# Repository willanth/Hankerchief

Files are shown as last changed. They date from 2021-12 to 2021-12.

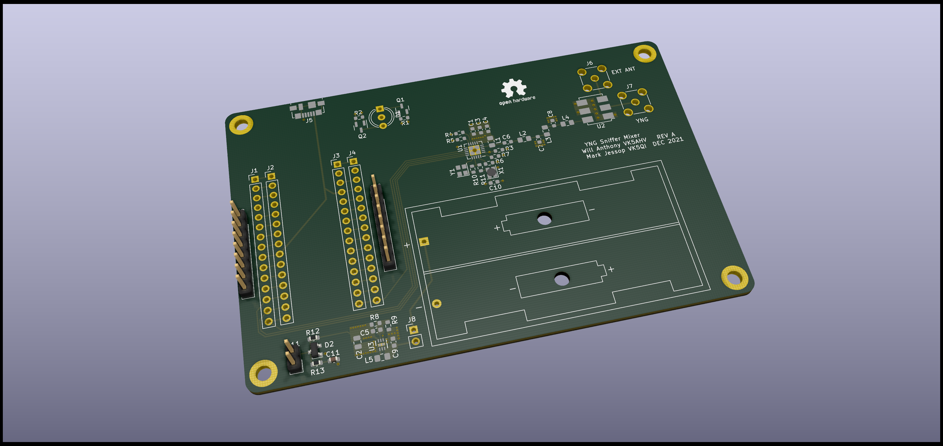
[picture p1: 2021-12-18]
sniffermixer2/sniffermixer2_RT.png

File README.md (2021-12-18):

# Hankerchief

This is a microcontroller driven signal source, used to extend the operating frequencies of the VK3YNG foxhunt sniffer.

The main components of this system are:
* STM32 Nuleo32 board (I used the L432KC) 
* Silabs Si4464 transciever chip
* ADE-1 mixer
* 3.3VDC boost converter suppled by 2x AA/LR6 batteries

There are provisions for user controls (J8 battery on/off, J11 shift frequency) as well as making use of the IO on the Nucleo module that isn't tied up operating the signal source.  There is a provsion for a bicolor LED, and for external 5V power input through a micro-B USB port.
**_IMPORTANT NOTE_**:  
* There is no battery charging facility through the USB power connector
* There is no USB Data access to the Nucleo32 through the USB power connector
* 3.3V Power is supplied by the Nucleo32 onboard regulator (500mA max) when USB power is connected
* The Nucleo32 is not configured for 5V supply and 3.3V source out of the box, it requires a simple modification (in Nucleo documentation, datasheets folder)

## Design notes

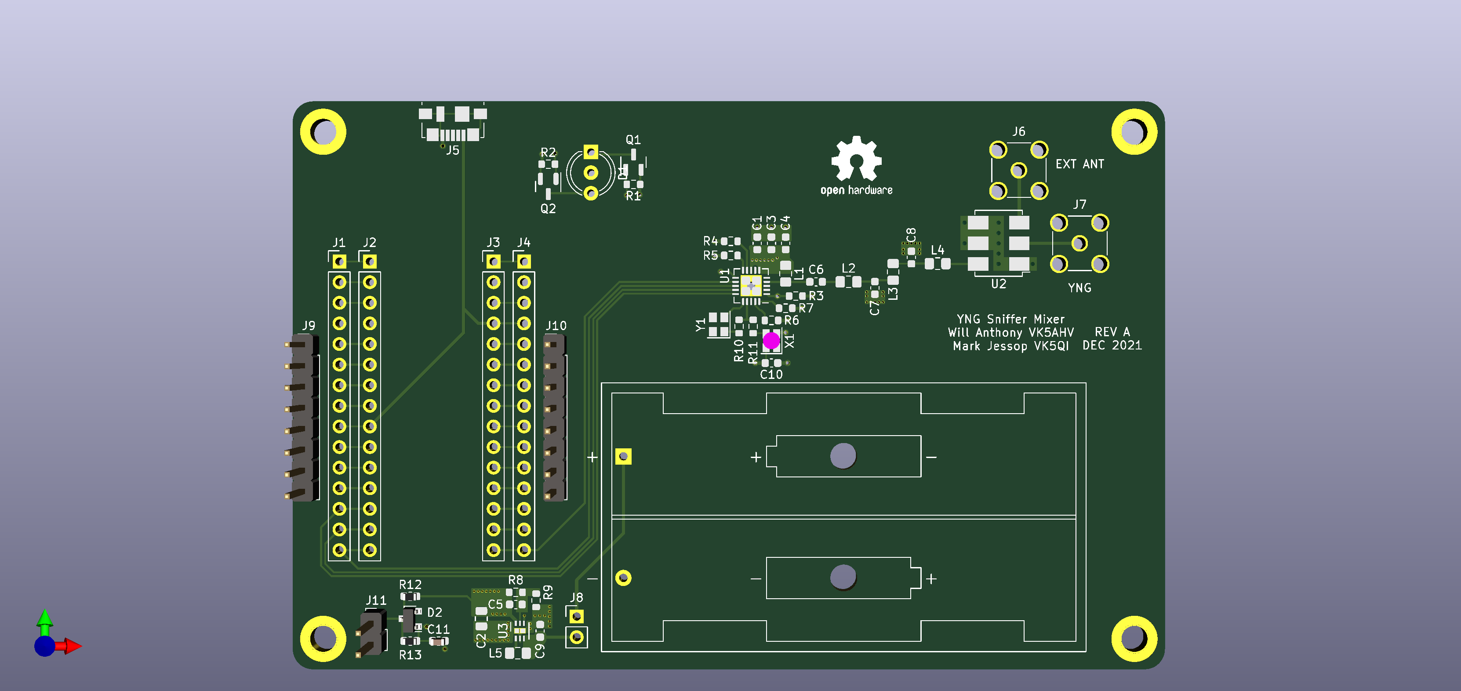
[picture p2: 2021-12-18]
sniffermixer2/sniffermixer2.png

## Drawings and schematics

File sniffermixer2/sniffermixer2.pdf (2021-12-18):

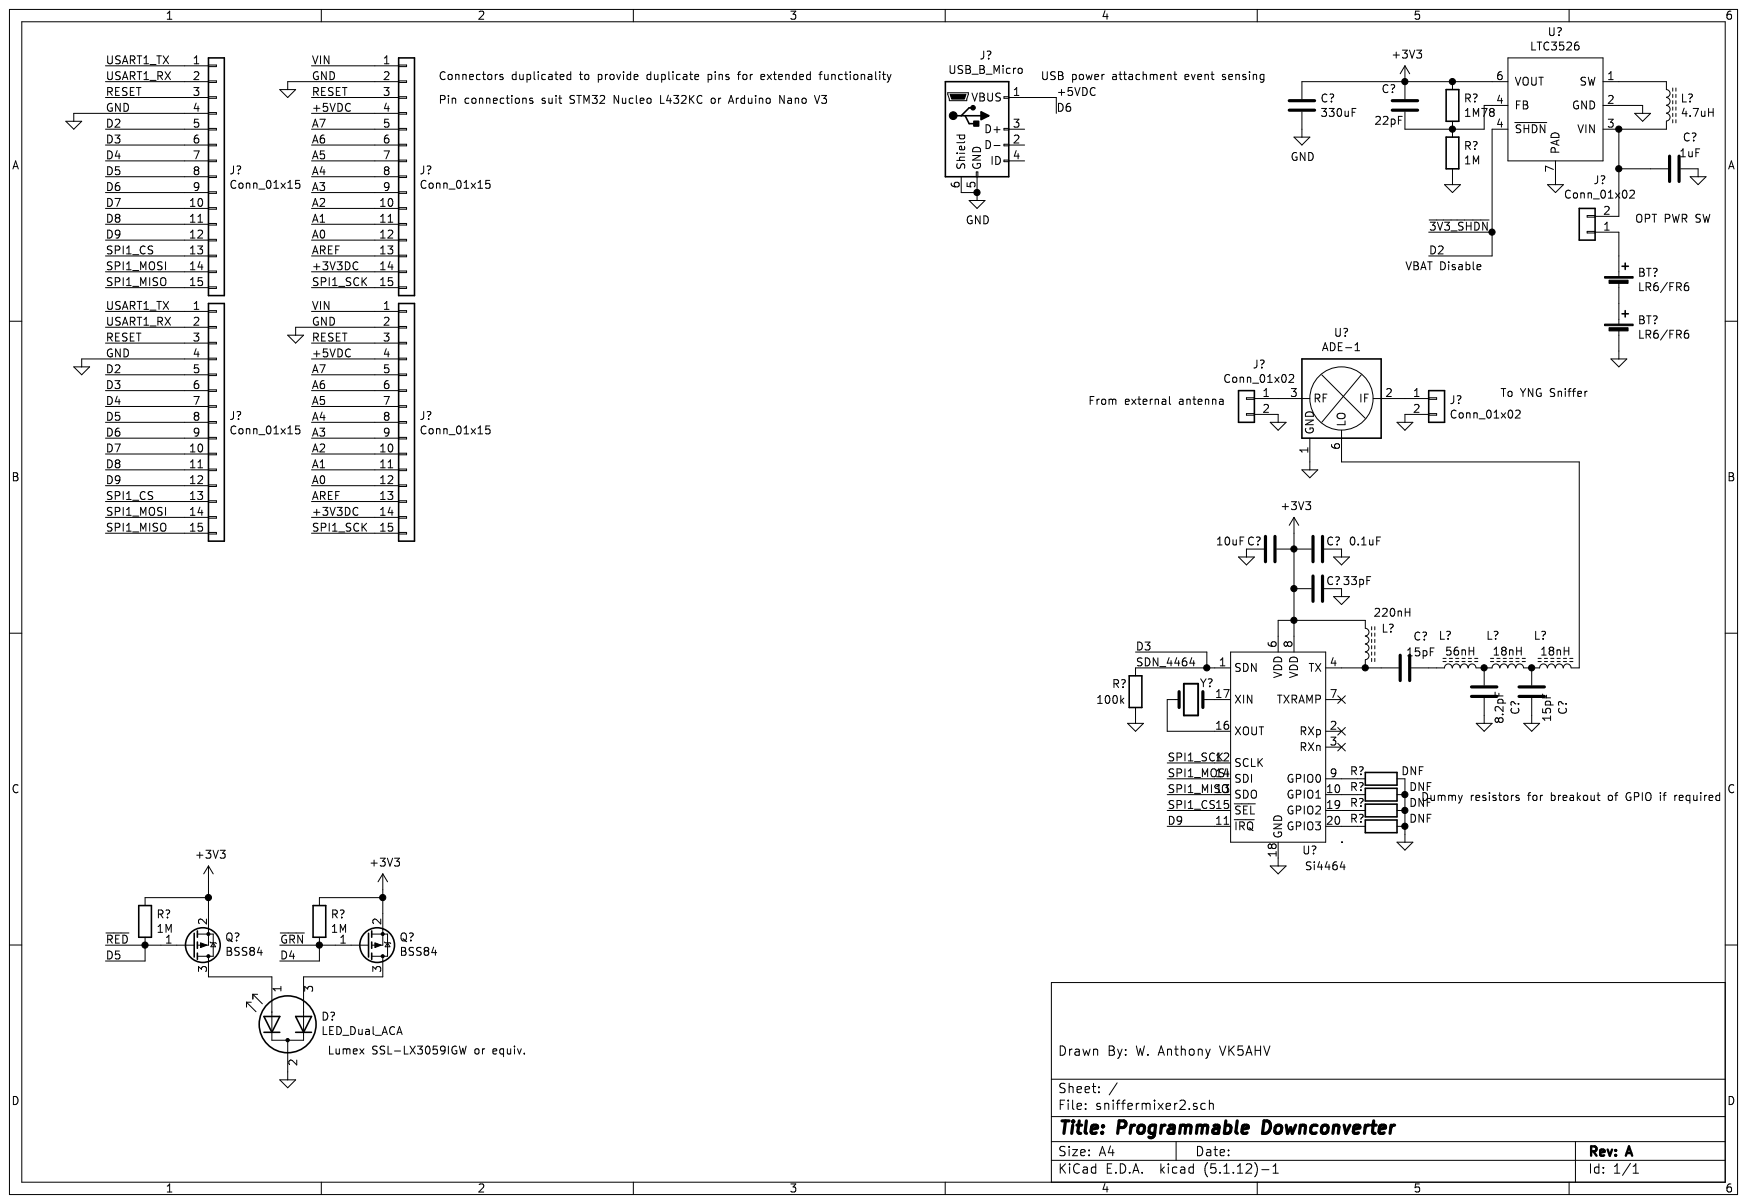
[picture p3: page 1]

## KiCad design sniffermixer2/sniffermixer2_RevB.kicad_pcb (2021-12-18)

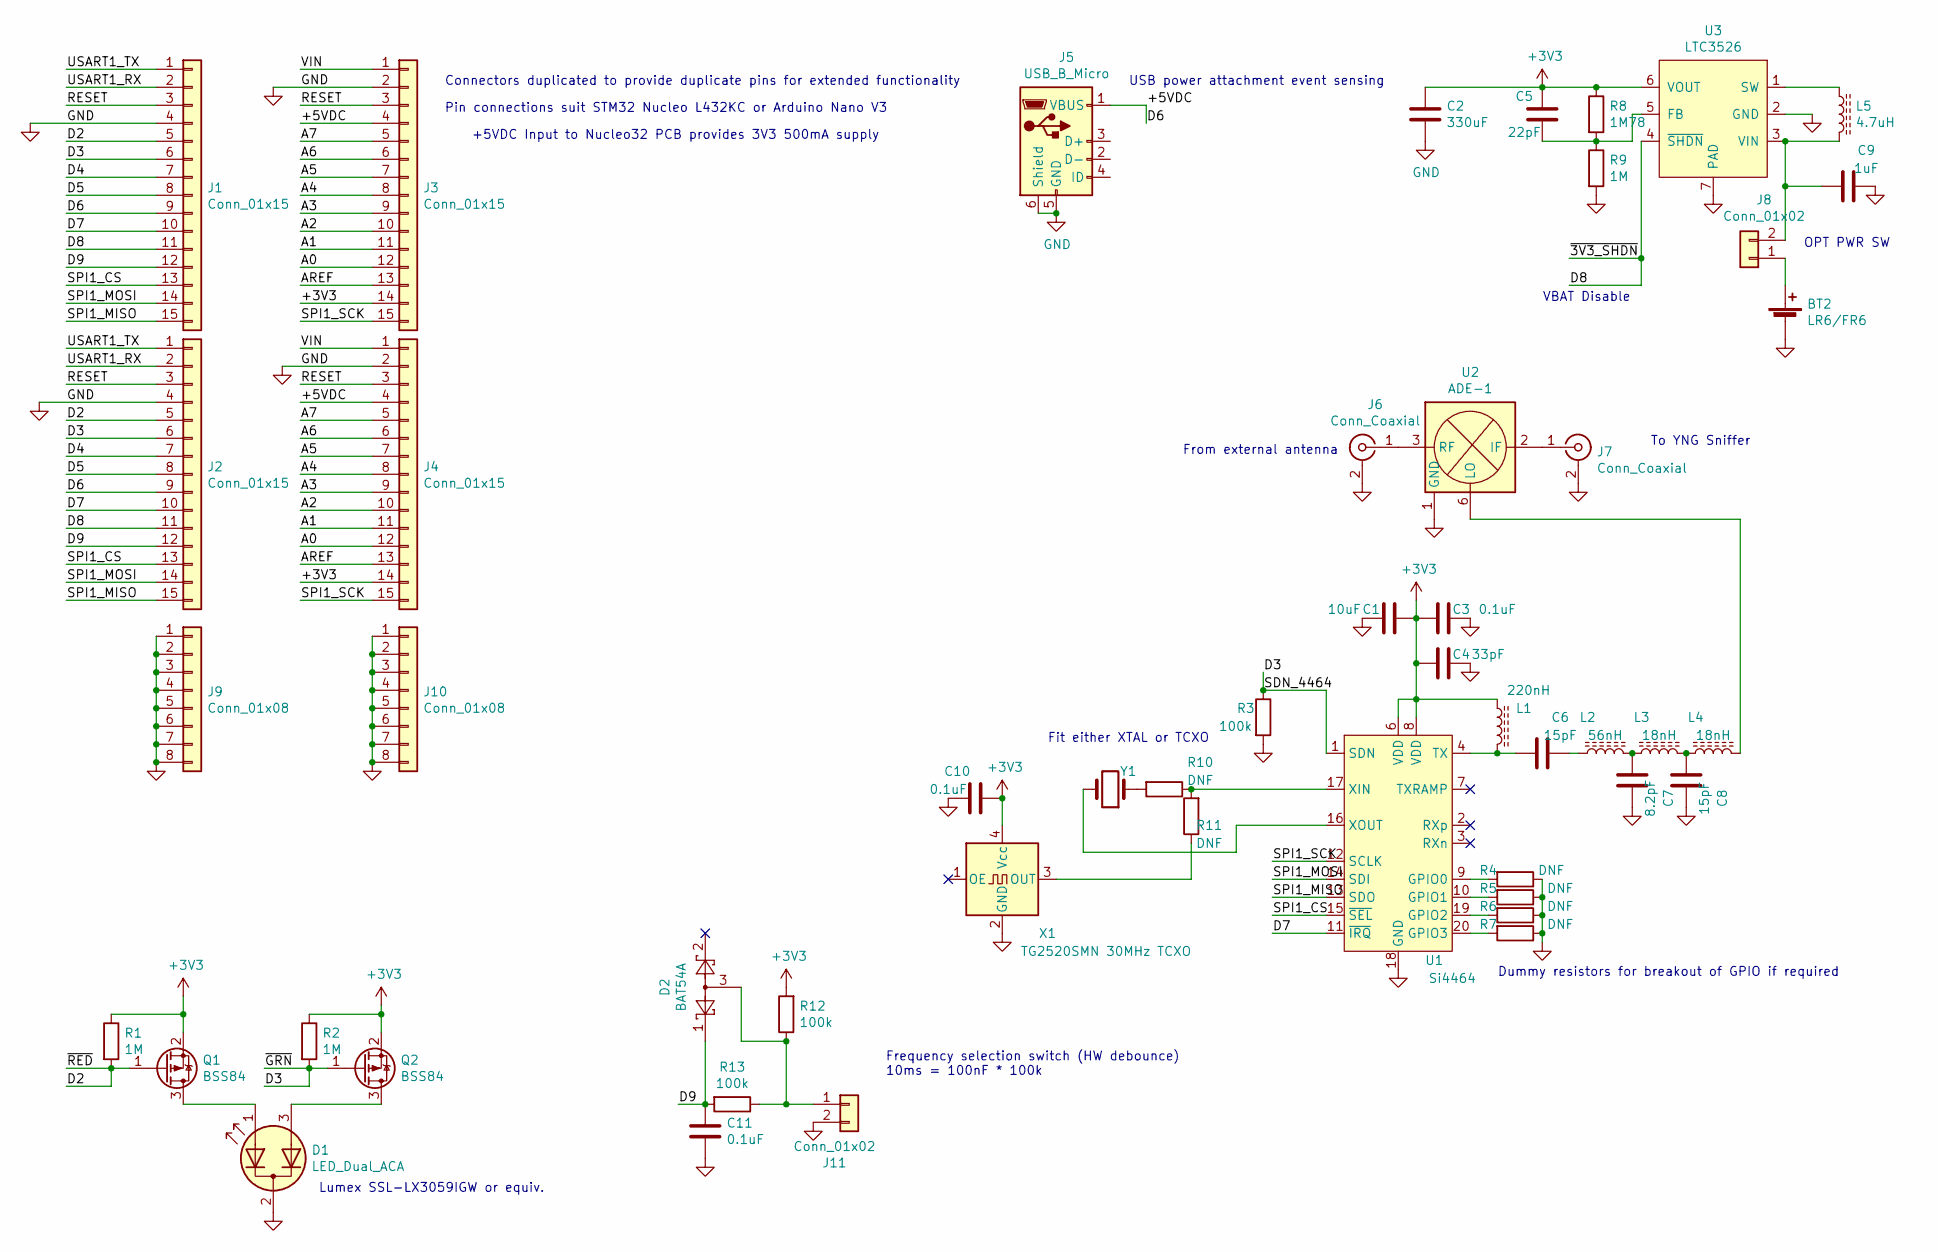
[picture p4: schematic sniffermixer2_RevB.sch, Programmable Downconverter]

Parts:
BT2: LR6/FR6; BatteryHolder_Keystone_2462_2xAA
C1: 10uF; C_0603_1608Metric
C2: 330uF; C_0805_2012Metric
C3, C10, C11: 0.1uF; C_0603_1608Metric
C4: 33pF; C_0603_1608Metric
C5: 22pF; C_0603_1608Metric
C6, C8: 15pF; C_0603_1608Metric
C7: 8.2pF; C_0603_1608Metric
C9: 1uF; C_0603_1608Metric
D1: LED_Dual_ACA; LED_D5.0mm-3
D2: BAT54A; SOT-23
J1, J2, J3, J4: Conn_01x15; PinHeader_1x15_P2.54mm_Vertical
J5: USB_B_Micro; USB_Micro-B_Molex_47346-0001
J6, J7: Conn_Coaxial; SMA_Amphenol_901-144_Vertical
J8, J11: Conn_01x02; PinHeader_1x02_P2.54mm_Vertical
J9, J10: Conn_01x08; PinHeader_1x08_P2.54mm_Vertical
L1: 220nH; L_0805_2012Metric_Pad1.15x1.40mm_HandSolder
L2: 56nH; L_0805_2012Metric_Pad1.15x1.40mm_HandSolder
L3, L4: 18nH; L_0805_2012Metric_Pad1.15x1.40mm_HandSolder
L5: 4.7uH; L_0805_2012Metric_Pad1.15x1.40mm_HandSolder
Q1, Q2: BSS84; SOT-23
R1, R2, R9: 1M; R_0603_1608Metric
R3, R12, R13: 100k; R_0603_1608Metric
R4, R5, R6, R7, R10, R11: DNF; R_0603_1608Metric
R8: 1M78; R_0603_1608Metric
U1: Si4464; QFN-20-1EP_4x4mm_P0.5mm_EP2.6x2.6mm
U2: ADE-1; Mini-Circuits_CD542_LandPatternPL-052
U3: LTC3526; DFN-6-1EP_2x2mm_P0.5mm_EP0.61x1.42mm
X1: TG2520SMN 30MHz TCXO; Oscillator_SMD_SeikoEpson_SG210-4Pin_2.5x2.0mm
Y1: Crystal; Crystal_SMD_2520-4Pin_2.5x2.0mm

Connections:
+3V3: C1.1, C2.1, C3.2, C4.2, C5.2, C10.2, J3.14, J4.14, L1.1, Q1.2 (S), Q2.2 (S), R1.1, R2.1, R8.1, R12.2, U1.6 (VDD), U1.8 (VDD), U3.6 (VOUT), X1.4 (Vcc)
/+5VDC: J1.9, J2.9, J3.4, J4.4, J5.1 (VBUS)
/A0: J3.12, J4.12
/A1: J3.11, J4.11
/A2: J3.10, J4.10
/A3: J3.9, J4.9
/A4: J3.8, J4.8
/A5: J3.7, J4.7
/A6: J3.6, J4.6
/A7: J3.5, J4.5
/AREF: J3.13, J4.13
/D2: J1.5, J2.5, Q1.1 (G), R1.2
/D7: J1.10, J2.10, U1.11 (~IRQ)
/D9: C11.1, D2.1, J1.12, J2.12, R13.2
/RESET: J1.3, J2.3, J3.3, J4.3
/SPI1_CS: J1.13, J2.13, U1.15 (~SEL)
/SPI1_MISO: J1.15, J2.15, U1.13 (SDO)
/SPI1_MOSI: J1.14, J2.14, U1.14 (SDI)
/SPI1_SCK: J3.15, J4.15, U1.12 (SCLK)
/USART1_RX: J1.2, J2.2
/USART1_TX: J1.1, J2.1
/VIN: J3.1, J4.1
GND: BT2.2 (-), C1.2, C2.2, C3.1, C4.1, C7.1, C8.1, C9.1, C10.1, C11.2, D1.2 (K), J1.4, J2.4, J3.2, J4.2, J5.5 (GND), J5.6 (Shield), J6.2 (Ext), J7.2 (Ext), J9.1, J9.2, J9.3, J9.4, J9.5, J9.6, J9.7, J9.8, J10.1, J10.2, J10.3, J10.4, J10.5, J10.6, J10.7, J10.8, J11.2, R3.2, R4.1, R5.1, R6.1, R7.1, R9.2, U1.18 (GND), U1.21 (GND), U2.1 (GND), U2.4 (GND), U2.5 (GND), U3.2 (GND), U3.7 (PAD), X1.2 (GND)
unnamed: BT2.1 (+), J8.1
unnamed: C5.1, R8.2, R9.1, U3.5 (FB)
unnamed: C6.1, L2.1
unnamed: C6.2, L1.2, U1.4 (TX)
unnamed: C7.2, L2.2, L3.1
unnamed: C8.2, L3.2, L4.1
unnamed: C9.2, J8.2, L5.2, U3.3 (VIN)
unnamed: D1.1 (A1), Q1.3 (D)
unnamed: D1.3 (A2), Q2.3 (D)
unnamed: D2.3, J11.1, R12.1, R13.1
unnamed: J6.1 (In), U2.3 (RF)
unnamed: J7.1 (In), U2.2 (IF)
unnamed: L4.2, U2.6 (LO)
unnamed: L5.1, U3.1 (SW)
unnamed: R4.2, U1.9 (GPIO0)
unnamed: R5.2, U1.10 (GPIO1)
unnamed: R6.2, U1.19 (GPIO2)
unnamed: R7.2, U1.20 (GPIO3)
unnamed: R10.1, R11.2, U1.17 (XIN)
unnamed: R10.2, Y1.1
unnamed: R11.1, X1.3 (OUT)
unnamed: U1.16 (XOUT), Y1.2

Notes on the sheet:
Connectors duplicated to provide duplicate pins for extended functionality
Pin connections suit STM32 Nucleo L432KC or Arduino Nano V3
Lumex SSL-LX3059IGW or equiv.
To YNG Sniffer
From external antenna
USB power attachment event sensing
VBAT Disable
OPT PWR SW
Dummy resistors for breakout of GPIO if required
Fit either XTAL or TCXO
+5VDC Input to Nucleo32 PCB provides 3V3 500mA supply
Frequency selection switch (HW debounce) 10ms = 100nF * 100k

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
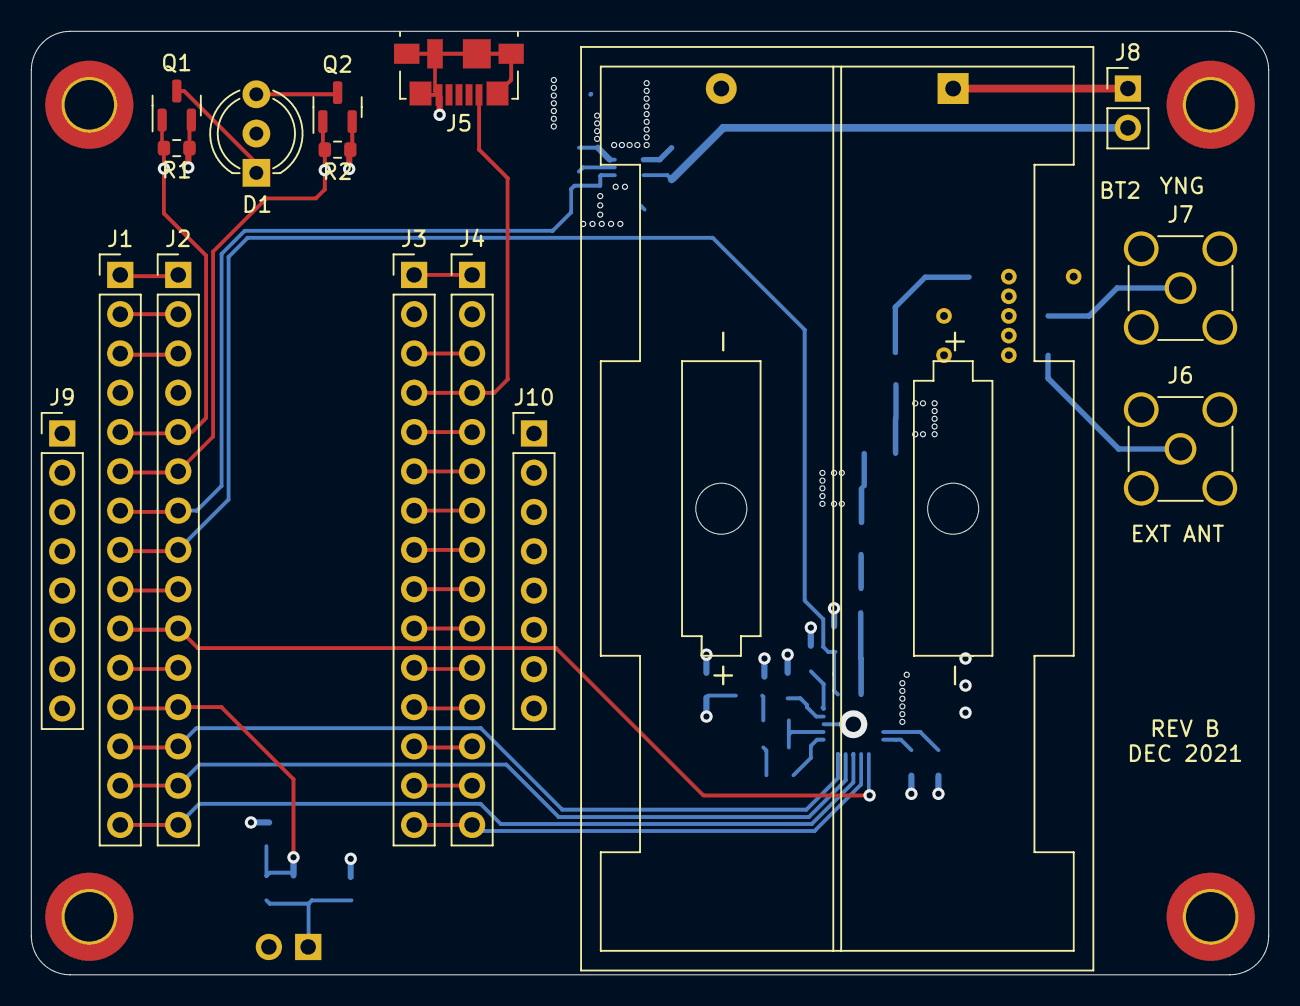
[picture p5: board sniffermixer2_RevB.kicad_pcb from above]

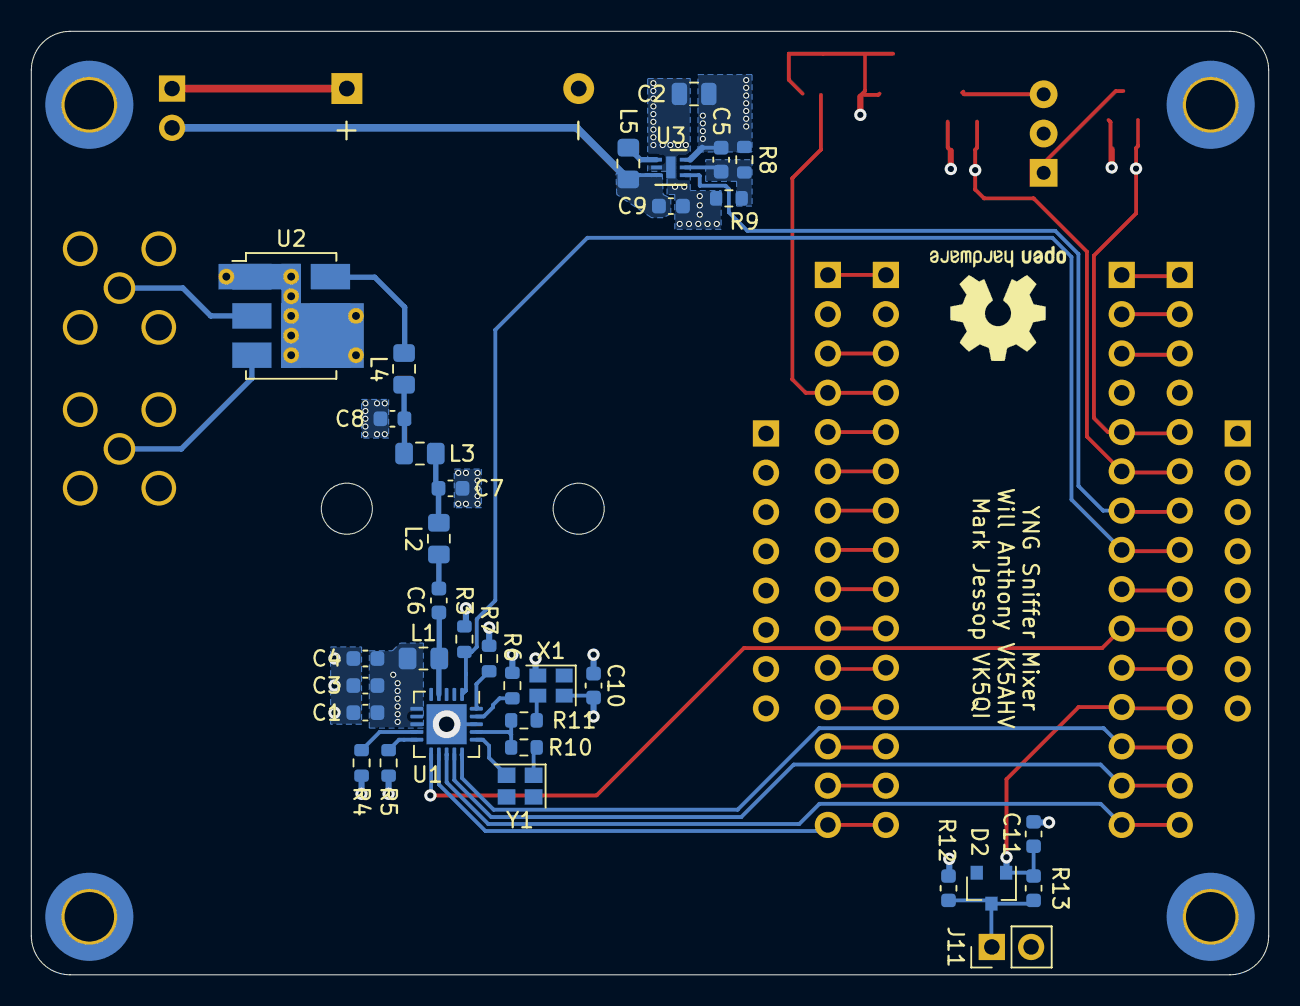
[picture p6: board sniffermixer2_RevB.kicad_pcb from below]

Board: 4 copper layers, 80.0 x 61.0 mm, 50 parts (34 on the bottom side), 49 nets.

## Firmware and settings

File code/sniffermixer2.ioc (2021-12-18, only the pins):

Mcu.UserName=STM32L432KCUx
PA0.GPIO_Label=MCO [High speed clock in]
PB0.GPIO_Label=SHDN_4464
PB6.GPIO_Label=LED_RED
PA12.Signal=GPIO_Output
PB6.Signal=GPIO_Output
PB1.GPIO_Label=USB_PWR_SENSE
PB7.Signal=GPIO_Output
PA8.Signal=GPXTI8
PA0.Signal=RCC_CK_IN
PB7.GPIO_Label=LED_GRN
PA6.Signal=SPI1_MISO
PB1.Signal=GPXTI1
PA2.GPIO_Label=VCP_TX
PA12.GPIO_Label=SHDN_VBAT
PA8.GPIO_Label=SI4464_IRQ
PA1.Signal=SPI1_SCK
PA2.Signal=USART2_TX
PA4.Signal=SPI1_NSS
PB0.Signal=GPIO_Output
PA7.Signal=SPI1_MOSI

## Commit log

2021-07-05 Project start some basic schematic capture performed
    [sniffermixer2.kicad_pcb, sniffermixer2.sch]
2021-07-05 some minor schematic capture: dupe connectors, tricolor LED, wiring
    [sniffermixer2.sch]
2021-12-18 Revision B hardware finalized and ready for production
    [sniffermixer2.kicad_pcb, sniffermixer2.sch]
2021-12-18 Update README.md
    added additional information around USB powering of the device
